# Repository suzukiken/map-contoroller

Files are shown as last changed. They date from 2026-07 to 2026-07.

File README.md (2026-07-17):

# map-controllor

車載向けの地図ナビアプリと、それを操作する USB コントローラー一式です。
コントローラー（QMK キーボード）からのキー入力で、地図のスクロール・ズーム・目的地設定などを行います。

**ナビアプリ** は Android 版と iOS（iPad）版があります。いずれも同じキー操作に対応しています。

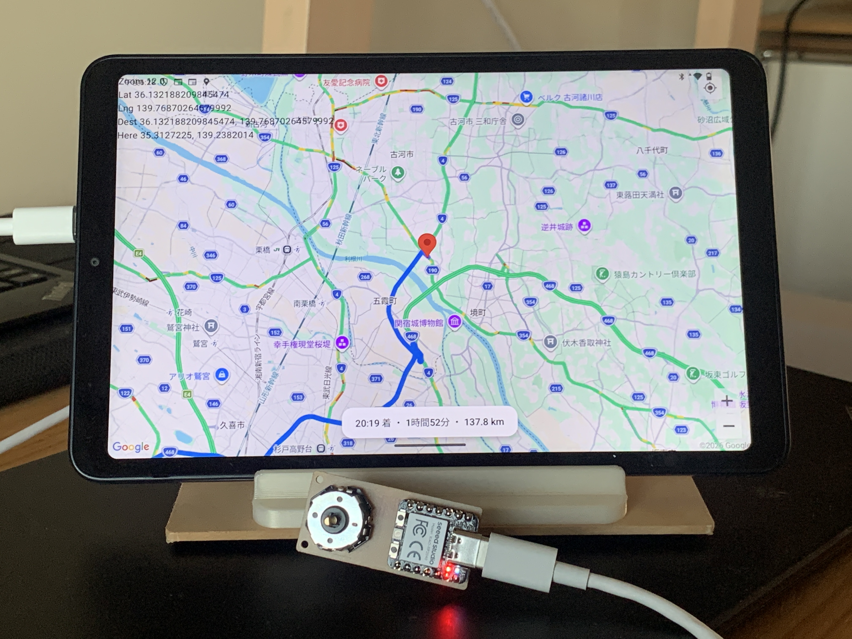
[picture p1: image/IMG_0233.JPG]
ナビアプリとコントローラー


## リポジトリ構成

| ディレクトリ | 内容 |
| --- | --- |
| [`android/`](android/) | Google Maps ベースのナビ Android アプリ |
| [`ios/`](ios/) | 同上の iOS / iPad 版（MapKit + Google Routes/Places API） |
| [`firmware/`](firmware/) | QMK ファームウェア（HID キーボード） |
| [`pcb/`](pcb/) | KiCad 基板データ |
| [`enclosure/`](enclosure/) | ケース・エンコーダノブ（OpenSCAD） |

## 使い方の流れ

1. [`pcb/`](pcb/) の基板を製造・実装し、[`enclosure/`](enclosure/) のケースに組み込む
2. [`firmware/`](firmware/) をビルドして XIAO RP2040 に書き込む
3. コントローラーを Android 端末または iPad に USB 接続する
4. ナビアプリ（[`android/`](android/) または [`ios/`](ios/)）を起動する

## ナビアプリ

USB 接続の map-controllor から送られるキー入力で地図を操作します。

| 操作 | キー | 動作 |
| --- | --- | --- |
| パン | 方向キー（長押し） | 地図スクロール |
| ズームイン | Page Up | ズーム +1 |
| ズームアウト | Page Down | ズーム -1 |
| 目的地設定 | Enter | 画面中心を目的地に設定し、ルート表示 |
| 現在地へ | Space | 現在地を中心に表示 |
| 音声入力 | V | 音声 → 住所検索 → 目的地設定 |
| 駐車場 | P | 近くの駐車場表示トグル |

コントローラー側のキー割り当て（スティック・エンコーダ・プッシュ）は [`firmware/README.md`](firmware/README.md) を参照してください。

### Google Maps API キー

ルート案内・駐車場検索に Google Routes / Places API を使います。Android / iOS で同じ API キーを使えます。

| プラットフォーム | 設定ファイル |
| --- | --- |
| Android | `android/local.properties` の `MAPS_API_KEY`（[`local.properties.example`](android/local.properties.example) をコピー） |
| iOS | `ios/Secrets.xcconfig` の `MAPS_API_KEY`（[`Secrets.xcconfig.example`](ios/Secrets.xcconfig.example) をコピー） |

Google Cloud Console で **Routes API** と **Places API (New)** を有効化してください。

### Android

[Maps SDK for Android](https://developers.google.com/maps/documentation/android-sdk) を使ったキーボード操作対応アプリです。

セットアップ・ビルド手順は [`android/README.md`](android/README.md) を参照してください。

### iOS

iPad 向けアプリです。地図表示は **MapKit**、ルート・駐車場検索は Android 版と同じ REST API を使います。

```bash
cp ios/Secrets.xcconfig.example ios/Secrets.xcconfig
# MAPS_API_KEY を設定
```

Xcode で [`ios/Navi.xcodeproj`](ios/Navi.xcodeproj) を開き、実機（iPad）で Run してください。初回は iPad の **設定 → 一般 → VPNとデバイス管理** で開発者アプリを信頼する必要があります。

詳細は [`ios/README.md`](ios/README.md) を参照してください。

## ハードウェア

ナビアプリを操作する物理コントローラーです。

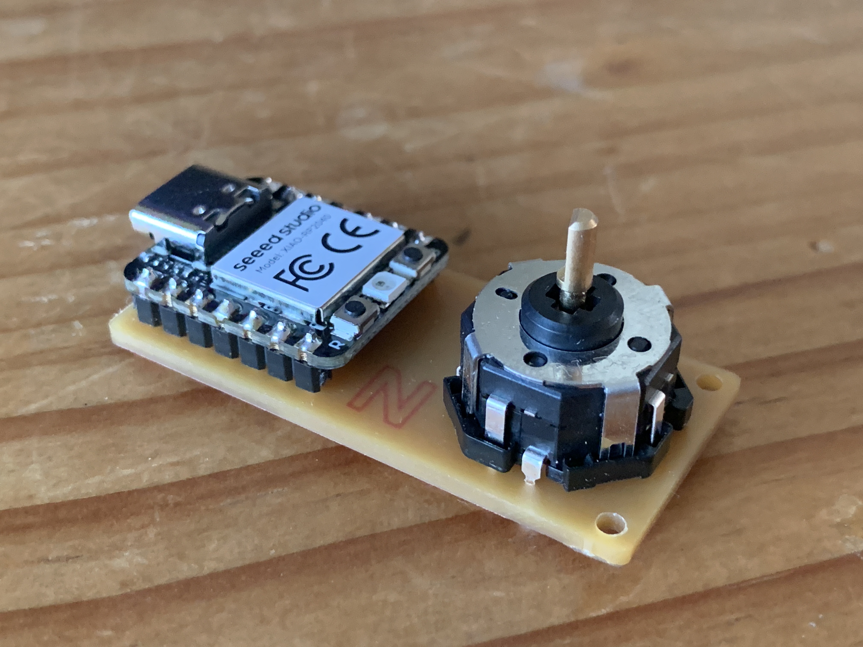
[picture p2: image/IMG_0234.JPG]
コントローラー試作


| 部品 | 説明 |
| --- | --- |
| [Alps RKJXT1F42001](https://tech.alpsalpine.com/j/products/detail/RKJXT1F42001/) | 4 方向スイッチ + プッシュ + ロータリーエンコーダ |
| [Seeed XIAO RP2040](https://wiki.seeedstudio.com/ja/XIAO-RP2040/) | USB 接続のマイコン（QMK ファームウェアを書き込む） |

基板データは [`pcb/`](pcb/) にあります。製造制約・配線ルール・回路設計の詳細は [`pcb/AGENTS.md`](pcb/AGENTS.md) を参照してください。

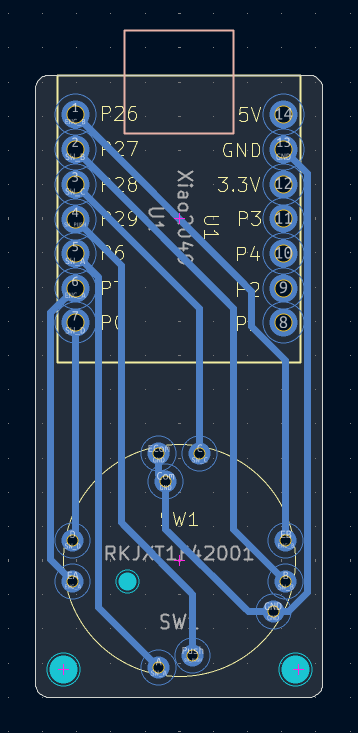
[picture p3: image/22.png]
基板レイアウト


## ファームウェア

[QMK](https://qmk.fm) でビルドする HID キーボード用のソースコードです。ここでいう **ファームウェア** は、工場出荷時に XIAO RP2040 に最初から入っているソフトではありません。利用者が自分でコンパイルして `.uf2` ファイルを生成し、USB 接続したハードウェアへ書き込むものです。

書き込み後、コントローラーの入力は USB 経由で接続先端末（Android または iPad）に送られます。ビルド・書き込み手順、キー割り当ては [`firmware/README.md`](firmware/README.md) を参照してください。

## ケース

基板と部品を収める 3D プリント用ケースです。[`enclosure/`](enclosure/) に OpenSCAD ソースと STL があります。

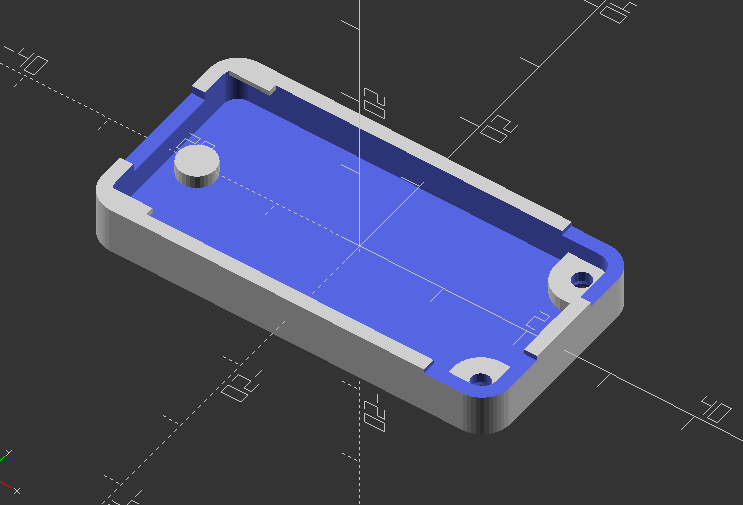
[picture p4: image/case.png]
ケース


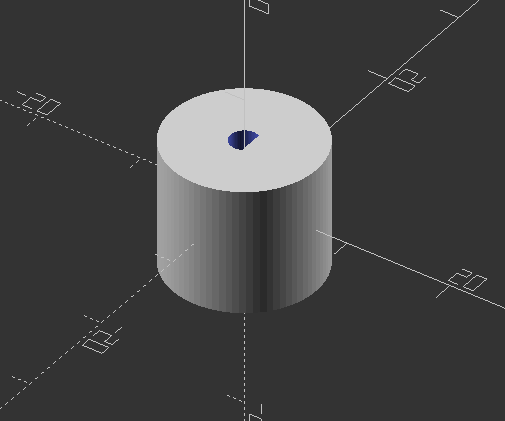
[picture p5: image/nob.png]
エンコーダノブ


| ファイル | 内容 |
| --- | --- |
| [`case.scad`](enclosure/case.scad) | 下ケース（基板 cavity・USB 切り欠き・ネジピラー） |
| [`knob.scad`](enclosure/knob.scad) | RKJXT1F42001 用エンコーダノブ |
| [`case.stl`](enclosure/case.stl) | 下ケース（出力済み STL） |
| [`knob.stl`](enclosure/knob.stl) | ノブ（出力済み STL） |

### 寸法・設計

基板 [`pcb/encoder.kicad_pcb`](pcb/encoder.kicad_pcb) の外形（21 × 45.5 mm、板厚 1.6 mm、角 R1 mm）に合わせています。

| 項目 | 値 |
| --- | --- |
| 基板サイズ | 21 × 45.5 mm |
| 取付穴 | (2, 2)、(19.25, 2) mm、φ2 mm |
| エンコーダ（SW1）中心 | 基板下辺から 10 mm |
| ノブ外径 | 14 mm |
| シャフト穴 | Ø2.5 mm（D カット、RKJXT1F42001 内側シャフト） |

下ケースは XIAO RP2040 下に中央支柱を 1 本置き、ピンヘッダとの干渉を避けています。USB-C コネクタ用の切り欠きは基板上辺側にあります。

### 組み立て

1. 下ケースに基板を載せ、取付穴位置 `(2, 2)` / `(19.25, 2)` から **M2 ネジ**を下側から通す
2. 基板上面に **M2 ナット**を載せて固定する
3. [`knob.scad`](enclosure/knob.scad) で出力したノブをエンコーダシャフトに取り付ける

### STL の再出力

[OpenSCAD](https://openscad.org/) で各 `.scad` を開き、**F6**（レンダリング）→ **F7**（STL 出力）で `case.stl` / `knob.stl` を生成できます。ノブのシャフト穴が合わない場合は `knob.scad` の `shaft_d` を微調整してください。

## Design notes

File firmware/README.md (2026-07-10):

# map-controllor firmware (QMK)

Seeed XIAO RP2040 + Alps RKJXT1F42001(4方向スイッチ + プッシュ + ロータリーエンコーダ)を
[QMK](https://qmk.fm) で HID キーボード化し、`android/` の地図アプリのコントローラーとして使う。

## ピン割り当て(pcb/encoder.kicad_pcb と対応)

| RKJXT1F42001 端子 | XIAO RP2040 ピン | 機能 |
| --- | --- | --- |
| A | GP6 (D4) | 下スクロール (↓) |
| B | GP27 (D1) | 右スクロール (→) |
| C | GP28 (D2) | 上スクロール (↑) |
| D | GP0 (D6) | 左スクロール (←) |
| Push | GP29 (D3) | Enter (目的地セット) |
| EA | GP7 (D5) | エンコーダ A相 |
| EB | GP26 (D0) | エンコーダ B相 |
| Com / ECom / GND | GND | 共通 |

## 操作と地図アプリの対応

| 操作 | 送信キー | アプリの動作 |
| --- | --- | --- |
| スティック上下左右 | ↑↓←→ | 地図スクロール |
| エンコーダ時計回り | PageUp | ズームイン |
| エンコーダ反時計回り | PageDown | ズームアウト |
| プッシュ | Enter | 画面中心を目的地にセット |

RKJXT1F42001 は方向を倒すと Push も同時に ON になる（部品仕様）。
`map_controllor.c` で方向入力中の Enter を無視している。

方向スイッチ A〜D の向きは実装の向きで変わるので、逆だったら
`keymaps/default/keymap.json` の `KC_UP/KC_DOWN/KC_LEFT/KC_RGHT` を入れ替える。

## ビルド

ビルド済みの `map_controllor_default.uf2` がこのディレクトリに入っている。
再ビルドする場合、リポジトリ直下の `.build/qmk_firmware` に QMK 環境をセットアップ済み
(`keyboards/map_controllor` がこのディレクトリへのシンボリックリンクになっている):

```bash
cd ~/qmk_firmware
qmk compile -kb map_controllor -km default
```

`map_controllor_default.uf2` が生成される。

`map_controllor.c` は Push フィルタ用。QMK が `keyboards/map_controllor/map_controllor.c` として自動でコンパイルする。
**`rules.mk` に `SRC += map_controllor.c` を書くと二重コンパイルでリンクエラーになるので不要。**

## 書き込み

1. XIAO RP2040 の **BOOT** ボタンを押しながら USB 接続(または BOOT を押しながら RESET)
2. マウントされた `RPI-RP2` ドライブに **`map_controllor_default.uf2`** をコピーすると自動で再起動して完了

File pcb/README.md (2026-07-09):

# map-controllor PCB (KiCad)

Seeed XIAO RP2040 (U1) と Alps RKJXT1F42001 (SW1) を載せる基板データです。

基板設計の仕様（製造制約・配線ルール・配線案）は [`AGENTS.md`](AGENTS.md) を参照してください。
AI エージェントに設計を任せる場合は、まず `AGENTS.md` を読ませてください。

## 構成

## 結線

| SW1 (RKJXT1F42001) | ネット | U1 (XIAO RP2040) |
| --- | --- | --- |

スイッチ・エンコーダの共通端子はすべて GND に落とし、
RP2040 の内蔵プルアップ(QMK の direct pins / encoder デフォルト)で読む。
外付け部品は不要。

## ファイル

- `encoder.kicad_pro` / `encoder.kicad_pcb` — KiCad 10 プロジェクト
- `footpritn/footpritn.pretty/` — XIAO RP2040 と RKJXT1F42001 のフットプリント
- `scripts/` — 配線・検証に使った pcbnew スクリプト
- `render_top.png` / `render_bottom.png` — レンダリング画像

## 検証

```bash
/Applications/KiCad/KiCad.app/Contents/MacOS/kicad-cli pcb drc encoder.kicad_pcb
```

エラー0件・未結線0件(シルクとマスクの重なり警告のみ)。

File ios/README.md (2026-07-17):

# iOS ナビアプリ

Android 版（`android/`）と同じキーボード操作対応の地図ナビアプリです。

## 機能

| 操作 | キー | 動作 |
| --- | --- | --- |
| パン | 方向キー（長押し） | 地図スクロール（120ms 間隔） |
| ズームイン | Page Up | ズーム +1 |
| ズームアウト | Page Down | ズーム -1 |
| 目的地設定 | Enter | 画面中心を目的地に設定 |
| 現在地へ | Space | 現在地を中心に表示 |
| 音声入力 | V | 音声 → 住所検索 → 目的地設定 |
| 駐車場 | P | 近くの駐車場表示トグル |

地図表示は MapKit、ルート・駐車場検索は Google Routes / Places API（Android と同じ REST API）を使います。

## セットアップ

1. API キーを設定（Android と同じキーで可）:
   ```bash
   cp Secrets.xcconfig.example Secrets.xcconfig
   # Secrets.xcconfig を編集して MAPS_API_KEY を設定
   ```
   キーは `AppInfo.plist` 経由でアプリに渡されます（`Secrets.xcconfig` → ビルド設定 `MAPS_API_KEY`）。
2. Xcode で `ios/Navi.xcodeproj` を開く
3. 実機（iPad）を接続し Run

### API キーの制限

Google Cloud Console で次の API を有効化してください。

- Routes API
- Places API (New)

iOS 向けに Maps SDK for iOS の制限は不要です（MapKit 使用）。REST API 用のキー制限を設定してください。

## キー操作

USB 接続の map-controllor コントローラー（QMK キーボード）を iPad に接続して使います。Android 版と同じキーマップです。

## プロジェクト構成

```
ios/
├── Navi.xcodeproj
├── AppInfo.plist          # MAPS_API_KEY を Info.plist へ渡す
├── Secrets.xcconfig.example
├── Secrets.xcconfig       # git 管理外（ローカル設定）
├── Navi/
│   ├── Models/
│   ├── Services/
│   ├── ViewModels/
│   └── Views/
├── NaviTests/
└── NaviUITests/
```

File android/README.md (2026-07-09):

# android-my-car-navi

車載向けナビゲーション Android アプリ（開発用リポジトリ: `android-my-car-navi`）。




## 目次
- [概要](#概要)
- [機能](#機能)
- [前提条件](#前提条件)
- [セットアップ](#セットアップ)
- [ビルドと実行](#ビルドと実行)
- [テスト](#テスト)
- [開発フロー](#開発フロー)
- [ディレクトリ構成](#ディレクトリ構成)
- [貢献](#貢献)
- [ライセンス](#ライセンス)
- [連絡先](#連絡先)

## 概要
このリポジトリは Android アプリ「android-my-car-navi」のソースコードを含みます。車載向けに設計されたナビアプリで、現在地表示、ルート案内、地図データの扱いなどの機能を計画・実装しています。

## 機能
- 現在地の取得と表示（GPS）
- ルート検索・表示（将来的に音声ナビ対応を予定）
- 地図タイルのキャッシュ管理
- 設定とユーザープロファイル（実装中）

（実装済み/未実装の詳細は Issue / プロジェクトボードを参照してください）

## 前提条件
- JDK 11 以上
- Android SDK（プロジェクトの `compileSdk` に合わせる）
- Android Studio（推奨）またはコマンドラインの Gradle ラッパー
- `local.properties` に Android SDK パスを設定（`local.properties.example` を参照）

重要: `local.properties` は環境依存のため通常コミットしません。リポジトリにある `local.properties.example` をコピーして利用してください。

## セットアップ
1. リポジトリをクローン:
   ```bash
   git clone <your-repo-url>
   cd android-my-car-navi

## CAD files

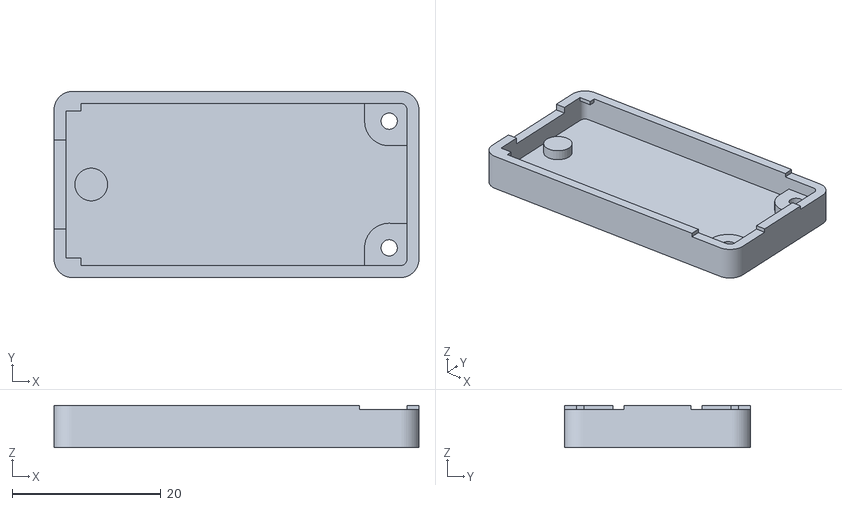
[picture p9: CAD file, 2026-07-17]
enclosure/case.stl
49.0 x 25.0 x 5.70

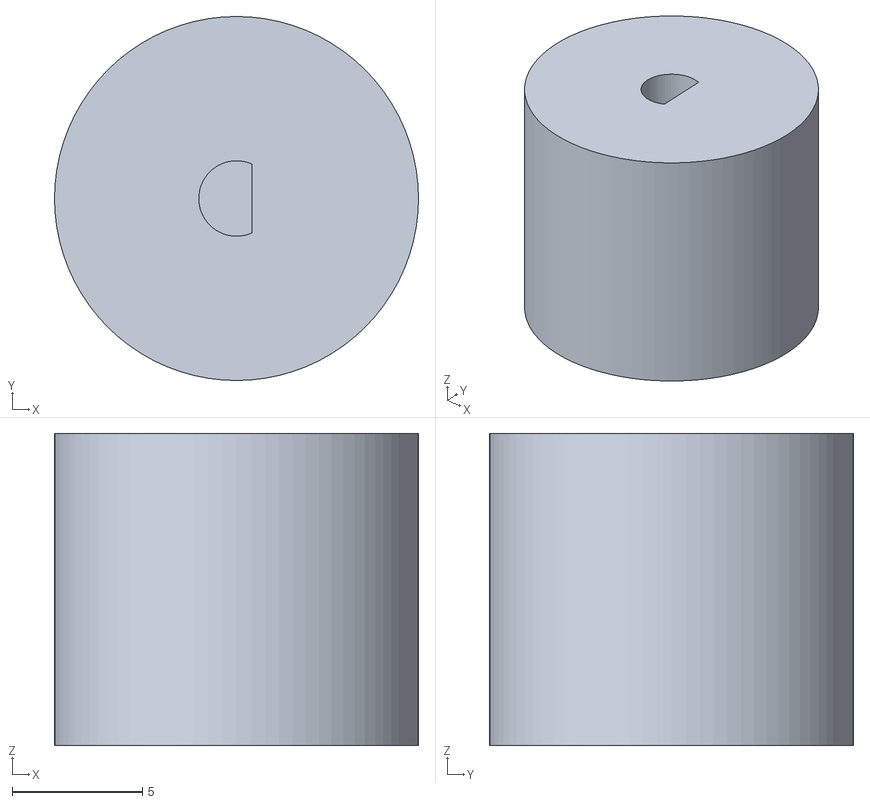
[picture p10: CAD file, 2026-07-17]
enclosure/knob.stl
14.0 x 14.0 x 12.0

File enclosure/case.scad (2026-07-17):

padding = 1.6; // wall width
// a little space for inserting PCB, 0.5 is good for PETG
// 0.3 is good for PLA with 0.6 nozzle
board_margin = 0.4;
side_padding = padding + board_margin;
board_2_fook_margin = 0.3;
// board_depth = 1.6; // 0.8 or 1.6
board_under_space = 1.6;
board_corner_radius = 0.5;
fook_height = 0.6;
fook_length = 2;
fook_width = 1.0;
pico_width = 21;
pico_offset = 2;
screw_radius = 1.1;
screw_pillor_radius = 3.31;
pico_pillor_radius = 2.2;
screw_pillor_offset = 2.0;
screw_head_height = 1.7;
screw_head_radius = 2.3;
screw_head_margin = 0.3;
outer_corner_radius = board_corner_radius + side_padding;

// base bucket
module outer_bucket(board_w, board_h, depth) {
    minkowski()
    {
        cylinder_height = 1;
        cube([
            board_w + side_padding * 2 - outer_corner_radius * 2, 
            board_h + side_padding * 2 - outer_corner_radius * 2, 
            cylinder_height
        ], center=true);
        cylinder(
            r=outer_corner_radius,
            h=depth - cylinder_height, 
            center=true,
            $fn=50
        );
    }
}
// hole for board
module board_hole(board_w, board_h, depth) {
    minkowski()
    {
        cylinder_height = 1;
        cube([
            board_w + board_margin * 2 - (board_corner_radius + board_margin) * 2, 
            board_h + board_margin * 2 - (board_corner_radius + board_margin) * 2, 
            cylinder_height
        ], center=true);
        cylinder(
            r=board_corner_radius + board_margin,
            h=depth - cylinder_height - padding, 
            center=true,
            $fn=50
        );
    }
}

// hole for usb
module usb_hole() {
    cube([12, 12, 2], center=true); // usb hole
}

module screw_pillar(depth, withcube) {
    translate([0, 0, - (depth - padding) / 2 + board_under_space]) {
        cylinder(r=screw_pillor_radius, h=board_under_space, center=true, $fn=30);
    }
    if (withcube) {
        translate([- screw_pillor_radius + padding, padding + 0.04, - (depth - padding) / 2 + board_under_space]) {
            cube([screw_pillor_radius, screw_pillor_radius, board_under_space], center=true);
        }
        translate([padding + 0.04, - screw_pillor_radius + padding, - (depth - padding) / 2 + board_under_space]) {
            cube([screw_pillor_radius, screw_pillor_radius, board_under_space], center=true);
        }
    }
}

module screw_hole(depth) {
    hole_height = padding + board_under_space;
    translate([0, 0, - (depth - hole_height) / 2]) {
        cylinder(r=screw_radius, h=hole_height, center=true, $fn=20);
    }
    translate([0, 0, - (depth - screw_head_height) / 2 + screw_head_margin]) {
        #cylinder(r1=screw_head_radius, r2=screw_radius, h=screw_head_height, center=true, $fn=20);
    }
    translate([0, 0, - (depth - screw_head_margin) / 2]) {
        cylinder(r=screw_head_radius, h=screw_head_margin, center=true, $fn=20);
    }
    translate([0, 0, (depth - fook_height) / 2]) {
        rotate([0, 0, 0]) {
            cube([8, 8, fook_height], center=true, $fn=20);
        }
    }
}



module main(board_w, board_h, board_d) {
    depth = fook_height + board_d + board_2_fook_margin + board_under_space + padding;
    difference() {
        union() {
            difference() {
                outer_bucket(board_w, board_h, depth);
                translate([0, 0, padding / 2 + 0.01]) {
                    board_hole(board_w, board_h, depth);
                }
                // usb hole
                translate([
                    - board_w / 2, 
                    board_h / 2 - pico_width / 2, 
                    depth / 2
                ]) {
                    usb_hole();
                }
            }
            // center pillor under pico
            translate([
                - board_w / 2 + screw_pillor_offset + 1, 
                board_h / 2 - pico_width / 2, 
                - (depth - padding) / 2 + board_under_space
            ]) {
                cylinder(r=pico_pillor_radius, h=board_under_space, center=true, $fn=30);
            }

            // fooks
            translate([
                - (board_w - fook_length) / 2 - board_margin, 
                - (board_h - fook_width) / 2 - board_margin, 
                (depth - fook_height) / 2
                ]) {
                cube([fook_length, fook_width, fook_height], center=true);
            }
            
            translate([
                - (board_w - fook_length) / 2 - board_margin, 
                (board_h - fook_width) / 2 + board_margin, 
                (depth - fook_height) / 2
                ]) {
                cube([fook_length, fook_width, fook_height], center=true);
            }
            // screw_pillar
            translate([board_w / 2 - screw_pillor_offset, board_h / 2 - screw_pillor_offset, 0]) {
                rotate([0, 0, 180]) {
                    screw_pillar(depth, true);
                }
            }
            
            translate([board_w / 2 - screw_pillor_offset, - board_h / 2 + screw_pillor_offset, 0]) {
                rotate([0, 0, 90]) {
                    screw_pillar(depth, true);
                }
            }

        }

        translate([board_w / 2 - screw_pillor_offset, board_h / 2 - screw_pillor_offset, 0]) {
            rotate([0, 0, 90]) {
                screw_hole(depth);
            }
        }
        translate([board_w / 2 - screw_pillor_offset, - board_h / 2 + screw_pillor_offset, 0]) {
            rotate([0, 0, 0]) {
                screw_hole(depth);
            }
        }

    }
}

main(45, 21, 1.6);

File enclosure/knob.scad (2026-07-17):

// RKJXT1F42001 ロータリーエンコーダー用ノブ
// データシート: 内側金属シャフト Ø2.5 mm（D カット）
//
// OpenSCAD で F6 → F7 で STL 出力

// --- シャフト（RKJXT1F42001 内側シャフト） ---
shaft_d = 2.5;
shaft_flat_w = 2.0;      // D カット側の幅（フラット面）
shaft_bore_clearance = 0.4;
shaft_engagement = 6.0;  // シャフト突出 ~6.6 mm

// --- ノブ外形 ---
knob_d = 14.0;
knob_h = 12.0;
top_fillet_r = 1.5;

module d_shaft_bore(height) {
    bore_d = shaft_d + shaft_bore_clearance;
    difference() {
        cylinder(d = bore_d, h = height, center = true, $fn = 64);
        // D 型フラット（+X 側を削る）
        translate([1.2, 0, 0]) {
            cube([1.2, 3, height + 0.2], center = true);
        }
    }
}

module encoder_knob() {
    difference() {
        union() {
            cylinder(d = knob_d, h = knob_h, center = true, $fn = 80);
            // 上面を少し丸める
            translate([0, 0, knob_h / 2 - top_fillet_r]) {
                rotate_extrude($fn = 80) {
                    translate([knob_d / 2 - top_fillet_r, 0, 0]) {
                        circle(r = top_fillet_r, $fn = 32);
                    }
                }
            }
        }

        translate([0, 0, knob_h / 2 - shaft_engagement / 2]) {
            d_shaft_bore(shaft_engagement + 0.4);
        }
    }
}

encoder_knob();

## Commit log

2026-07-09 fix pcb manually
    [encoder.kicad_pcb]
2026-07-09 fix pcb and firm
    [encoder.kicad_pcb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]
2026-07-11 add case
    [case.scad, case.stl, knob.scad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]
2026-07-16 add ios app
    [case.scad, case.stl, knob.scad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]

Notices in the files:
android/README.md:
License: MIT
